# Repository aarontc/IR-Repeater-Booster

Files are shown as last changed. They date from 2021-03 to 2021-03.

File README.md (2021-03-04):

# IR Repeater Booster
This is a small electronic circuit to relay signals from an IR repeater over category (5/6) cabling using differential signalling to achieve very long runs.

It was based upon the ["Tunteil IR Remote Control Repeater"] from Amazon, sourced around December 2020. 
The device has a powered IR receiver that seems to accommodate a range of frequencies, operating from 5V DC and providing
an open-collector output. It then uses buffer transistors to drive up to 6 pairs of IR LEDs with a low value series resistor.

The IR receiver uses a 3.5mm TRS connector, where tip is output, ring is 5V, and sleeve is ground.

The Repeater Booster is designed to operate between the IR receiver and the "repeater" unit. 

This board is designed to be as inexpensive as is reasonably possible using JLCPCB's assembly service. 

["Tunteil IR Remote Control Repeater"]: https://amzn.to/3bettCj

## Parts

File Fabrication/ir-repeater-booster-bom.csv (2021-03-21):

Reference | Quantity | Value | Footprint | Datasheet | Description | JEDEC Package Name | Manufacturer Name | Manufacturer Part Number | Vendor 1 Link | Vendor 1 Name | Vendor 1 Part Number | Vendor 1 Price @1 | Vendor 1 Pricing Date | Package Comments
C1 C2 C3 C4 C5 C6 | 6 | 10u | Capacitor_SMD:C_1206_3216Metric | https://datasheet.lcsc.com/szlcsc/1810221112_Samsung-Electro-Mechanics-CL31A106KBHNNNE_C13585.pdf | 10uF ±10% 50V X5R 1206 Multilayer Ceramic Capacitors MLCC - SMD/SMT RoHS | 1206 | Samsung Electro-Mechanics | CL31A106KBHNNNE | https://lcsc.com/product-detail/Multilayer-Ceramic-Capacitors-MLCC-SMD-SMT_SAMSUNG_CL31A106KBHNNNE_10uF-106-10-50V_C13585.html/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 | LCSC | C13585 | $0.0611 | 2021-03-03
D1 | 1 | SS14 | Diode_SMD:D_SMA | https://datasheet.lcsc.com/szlcsc/2007141104_MDD-Microdiode-Electronics-SS14_C2480.pdf | 40V 1A 550mV @ 1A SMA(DO-214AC) Schottky Barrier Diodes (SBD) RoHS | DO-214AC | MDD(Microdiode Electronics) | SS14 | https://lcsc.com/product-detail/Schottky-Barrier-Diodes-SBD_MDD-Microdiode-Electronics-SS14_C2480.html/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 | LCSC | C2480 | $0.0164 | 2021-03-03
H1 H2 H3 H4 | 4 | MountingHole | MountingHole:MountingHole_3.2mm_M3 | ~
J1 | 1 | DC_IN | Connector_BarrelJack:BarrelJack_Wuerth_6941xx301002 | ~
J2 | 1 | RJ45_LED_Shielded | Footprints:RJ45-TH_B-1-1 | https://datasheet.lcsc.com/szlcsc/1811141116_BOOMELE-Boom-Precision-Elec-RJ45-B-1-1_C138392.pdf | RJ45 12 1 Through Hole Ethernet Connectors/Modular Connectors (RJ45 RJ11) RoHS |  | BOOMELE(Boom Precision Elec) | RJ45-B-1*1 | https://lcsc.com/product-detail/Ethernet-Connectors-Modular-Connectors-RJ45-RJ11_BOOMELE-Boom-Precision-Elec-RJ45-B-1-1_C138392.html/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 | LCSC | C138392 | $0.2518 | 2021-03-03
JP1 | 1 | Termination | Jumper:SolderJumper-2_P1.3mm_Bridged_RoundedPad1.0x1.5mm | ~
JP2 | 1 | Transmit | Jumper:SolderJumper-2_P1.3mm_Open_RoundedPad1.0x1.5mm | ~
R1 | 1 | 1k | Resistor_SMD:R_0603_1608Metric | https://datasheet.lcsc.com/szlcsc/1811141223_UNI-ROYAL-Uniroyal-Elec-0603WAF1001T5E_C21190.pdf | 1kΩ ±1% 0.1W ±100ppm/℃ 0603 Chip Resistor - Surface Mount RoHS | 0603 | UNI-ROYAL(Uniroyal Elec) | 0603WAF1001T5E | https://lcsc.com/product-detail/Chip-Resistor-Surface-Mount_Uniroyal-Elec-0603WAF1001T5E_C21190.html/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 | LCSC | C21190 | $0.0015 | 2013-03-03
R2 | 1 | 120 | Resistor_SMD:R_0603_1608Metric | https://datasheet.lcsc.com/szlcsc/1811021215_UNI-ROYAL-Uniroyal-Elec-0603WAF1200T5E_C22787.pdf | 120Ω ±1% 0.1W ±100ppm/℃ 0603 Chip Resistor - Surface Mount RoHS | 0603 | UNI-ROYAL(Uniroyal Elec) | 0603WAF1200T5E | https://lcsc.com/product-detail/Chip-Resistor-Surface-Mount_Uniroyal-Elec-0603WAF1200T5E_C22787.html/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 | LCSC | C22787 | $0.0014 | 2021-03-03
R3 | 1 | 10k | Resistor_SMD:R_0603_1608Metric | https://datasheet.lcsc.com/szlcsc/1811062009_UNI-ROYAL-Uniroyal-Elec-0603WAF1002T5E_C25804.pdf | 10kΩ ±1% 0.1W ±100ppm/℃ 0603 Chip Resistor - Surface Mount RoHS | 0603 | UNI-ROYAL(Uniroyal Elec) | 0603WAF1002T5E | https://lcsc.com/product-detail/Chip-Resistor-Surface-Mount_Uniroyal-Elec-0603WAF1002T5E_C25804.html/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 | LCSC | C25804 | $0.0016 | 2021-03-03
R4 | 1 | 560 | Resistor_SMD:R_0603_1608Metric | https://datasheet.lcsc.com/szlcsc/1811021213_UNI-ROYAL-Uniroyal-Elec-0603WAF5600T5E_C23204.pdf | 560Ω ±1% 0.1W ±100ppm/℃ 0603 Chip Resistor - Surface Mount RoHS | 0603 | UNI-ROYAL(Uniroyal Elec) | 0603WAF5600T5E | https://lcsc.com/product-detail/Chip-Resistor-Surface-Mount_Uniroyal-Elec-0603WAF5600T5E_C23204.html/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 | LCSC | C23204 | $0.0021 | 2021-03-20 | Imperial
R5 | 1 | 1k2 | Resistor_SMD:R_0603_1608Metric | https://datasheet.lcsc.com/szlcsc/1811021221_UNI-ROYAL-Uniroyal-Elec-0603WAF1201T5E_C22765.pdf | 1.2kΩ ±1% 0.1W ±100ppm/℃ 0603 Chip Resistor - Surface Mount RoHS | 0603 | UNI-ROYAL(Uniroyal Elec) | 0603WAF1201T5E | https://lcsc.com/product-detail/Chip-Resistor-Surface-Mount_Uniroyal-Elec-0603WAF1201T5E_C22765.html/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 | LCSC | C22765 | $0.0019 | 2021-03-20 | Imperial
TP1 | 1 | !RE | TestPoint:TestPoint_Pad_D2.0mm | ~
TP10 | 1 | GND | TestPoint:TestPoint_Pad_D2.0mm | ~
TP2 | 1 | DE | TestPoint:TestPoint_Pad_D2.0mm | ~
TP3 | 1 | RXD | TestPoint:TestPoint_Pad_D2.0mm | ~
TP4 | 1 | TXD | TestPoint:TestPoint_Pad_D2.0mm | ~
TP5 | 1 | A | TestPoint:TestPoint_Pad_D2.0mm | ~
TP6 | 1 | B | TestPoint:TestPoint_Pad_D2.0mm | ~
TP7 | 1 | 12V | TestPoint:TestPoint_Pad_D2.0mm | ~
TP8 | 1 | 5V | TestPoint:TestPoint_Pad_D2.0mm | ~
TP9 | 1 | 3V3 | TestPoint:TestPoint_Pad_D2.0mm | ~
TX1 RX1 | 2 | PJ-307C | Footprints:AUDIO-TH_PJ307C | https://datasheet.lcsc.com/szlcsc/1811040611_BOOMELE-Boom-Precision-Elec-PJ-307C_C16684.pdf | 3.5mm Plug-in headphone holder 5 Female Horizontal 3.5mm Audio & Video Connectors RoHS |  | BOOMELE(Boom Precision Elec) | PJ-307C | https://lcsc.com/product-detail/Audio-Video-Connectors_BOOMELE-Boom-Precision-Elec-PJ-307C_C16684.html | LCSC | C16684 | $0.0422 | 2021-03-03
U1 | 1 | HT7550-1 | Package_TO_SOT_SMD:SOT-89-3 | https://datasheet.lcsc.com/szlcsc/1811061932_Holtek-Semicon-HT7550-1_C16106.pdf | Fixed 30V 3.3V 55mV @ 1mA SOT-89(SOT-89-3) Dropout Regulators(LDO) RoHS | SOT-89-3 | Holtek Semicon | HT7550-1 | https://lcsc.com/product-detail/Low-Dropout-Regulators-LDO_HT7550-1_C16106.html/?href=jlc-SMT | LCSC | C16106 | $0.1669 | 2021-03-03
U2 | 1 | ST3485EBDR | Package_SO:SOIC-8_3.9x4.9mm_P1.27mm | https://datasheet.lcsc.com/szlcsc/1810181648_STMicroelectronics-ST3485EBDR_C75809.pdf | transceiver RS422, RS485 1/1 15Mbps SO-8 RS-485/RS-422 ICs RoHS | SO-8 | STMicroelectronics | ST3485EBDR | https://lcsc.com/product-detail/RS-485-RS-422-ICs_STMicroelectronics-ST3485EBDR_C75809.html/?href=jlc-SMT | LCSC | C75809 | $0.7574 | 2021-03-03
U3 | 1 | HT7533-1 | Package_TO_SOT_SMD:SOT-89-3 | https://datasheet.lcsc.com/szlcsc/1811062113_Holtek-Semicon-HT7533-1_C14289.pdf | Fixed 30V 3.3V 55mV @ 1mA SOT-89(SOT-89-3) Dropout Regulators(LDO) RoHS | SOT-89-3 | Holtek Semicon | HT7533-1 | https://lcsc.com/product-detail/Low-Dropout-Regulators-LDO_HT7533-1_C14289.html/?href=jlc-SMT | LCSC | C14289 | $0.1494 | 2021-03-03
U4 | 1 | 74HC14 | Package_SO:SOIC-14_3.9x8.7mm_P1.27mm | https://datasheet.lcsc.com/szlcsc/1811141851_Nexperia-74HC14D-653_C5605.pdf | 74HC Inverted器 6 6 2V ~ 6V SOIC-14_150mil Gates and Inverters RoHS | SOIC-14_150mil | Nexperia | 74HC14D,653 | https://lcsc.com/product-detail/74-Series_Nexperia_74HC14D-653_74HC14D-653_C5605.html/?href=jlc-SMT | LCSC | C5605 | $0.1116 | 2021-03-20 | SOIC-14_150mil

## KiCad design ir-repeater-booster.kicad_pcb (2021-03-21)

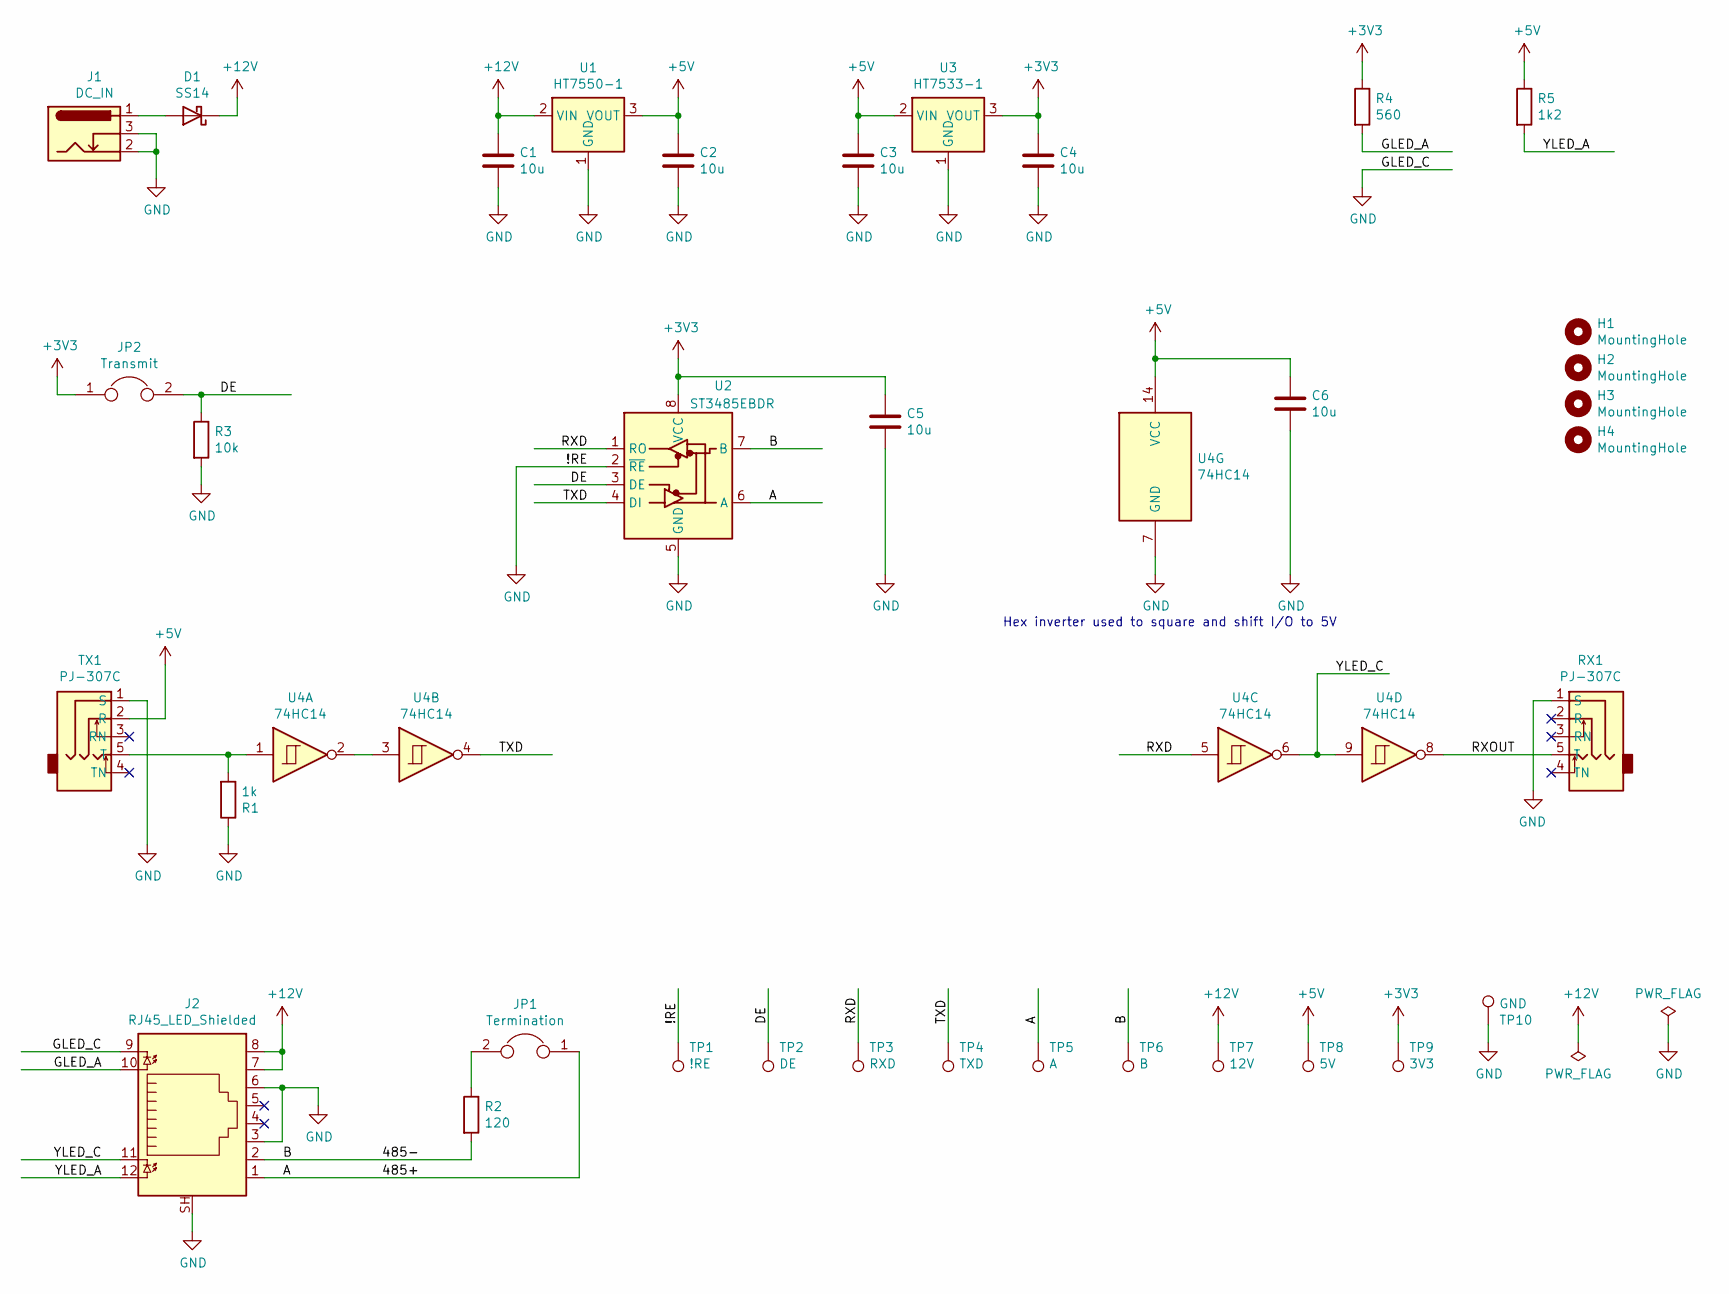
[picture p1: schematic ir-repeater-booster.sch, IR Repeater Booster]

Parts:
C1, C2, C3, C4, C5, C6: 10u; C_1206_3216Metric; Manufacturer Part Number CL31A106KBHNNNE
D1: SS14; D_SMA; Manufacturer Part Number SS14
H1, H2, H3, H4: MountingHole; MountingHole_3.2mm_M3
J1: DC_IN; BarrelJack_Wuerth_6941xx301002
J2: RJ45_LED_Shielded; RJ45-TH_B-1-1; Manufacturer Part Number RJ45-B-1*1
JP1: Termination; SolderJumper-2_P1.3mm_Bridged_RoundedPad1.0x1.5mm
JP2: Transmit; SolderJumper-2_P1.3mm_Open_RoundedPad1.0x1.5mm
R1: 1k; R_0603_1608Metric; Manufacturer Part Number 0603WAF1001T5E
R2: 120; R_0603_1608Metric; Manufacturer Part Number 0603WAF1200T5E
R3: 10k; R_0603_1608Metric; Manufacturer Part Number 0603WAF1002T5E
R4: 560; R_0603_1608Metric; Manufacturer Part Number 0603WAF5600T5E
R5: 1k2; R_0603_1608Metric; Manufacturer Part Number 0603WAF1201T5E
RX1: PJ-307C; AUDIO-TH_PJ307C; Manufacturer Part Number PJ-307C
TP1: !RE; TestPoint_Pad_D2.0mm
TP2: DE; TestPoint_Pad_D2.0mm
TP3: RXD; TestPoint_Pad_D2.0mm
TP4: TXD; TestPoint_Pad_D2.0mm
TP5: A; TestPoint_Pad_D2.0mm
TP6: B; TestPoint_Pad_D2.0mm
TP7: 12V; TestPoint_Pad_D2.0mm
TP8: 5V; TestPoint_Pad_D2.0mm
TP9: 3V3; TestPoint_Pad_D2.0mm
TP10: GND; TestPoint_Pad_D2.0mm
TX1: PJ-307C; AUDIO-TH_PJ307C; Manufacturer Part Number PJ-307C
U1: HT7550-1; SOT-89-3; Manufacturer Part Number HT7550-1
U2: ST3485EBDR; SOIC-8_3.9x4.9mm_P1.27mm; Manufacturer Part Number ST3485EBDR
U3: HT7533-1; SOT-89-3; Manufacturer Part Number HT7533-1
U4: 74HC14; SOIC-14_3.9x8.7mm_P1.27mm; Manufacturer Part Number 74HC14D,653

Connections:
+3V3: C4.1, C5.1, JP2.1, R4.1, TP9.1, U2.8 (VCC), U3.3 (VOUT)
+5V: C2.1, C3.1, C6.1, R5.1, TP8.1, TX1.2 (R), U1.3 (VOUT), U3.2 (VIN), U4.14 (VCC)
+12V: C1.1, D1.1 (K), J2.7, J2.8, TP7.1, U1.2 (VIN)
/485+: J2.1, JP1.1, TP5.1, U2.6 (A)
/485-: J2.2, R2.2, TP6.1, U2.7 (B)
/DE: JP2.2, R3.1, TP2.1, U2.3 (DE)
/GLED_A: J2.10, R4.2
/RXD: TP3.1, U2.1 (RO), U4.5
/RXOUT: RX1.5 (T), U4.8
/TXD: TP4.1, U2.4 (DI), U4.4
/YLED_A: J2.12, R5.2
/YLED_C: J2.11, U4.6, U4.9
GND: C1.2, C2.2, C3.2, C4.2, C5.2, C6.2, J1.2, J1.3, J2.3, J2.6, J2.9, J2.SH, R1.1, R3.2, RX1.1 (S), TP1.1, TP10.1, TX1.1 (S), U1.1 (GND), U2.2 (~RE), U2.5 (GND), U3.1 (GND), U4.7 (GND)
unnamed: D1.2 (A), J1.1
unnamed: JP1.2, R2.1
unnamed: R1.2, TX1.5 (T), U4.1
unnamed: U4.2, U4.3

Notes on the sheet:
Hex inverter used to square and shift I/O to 5V

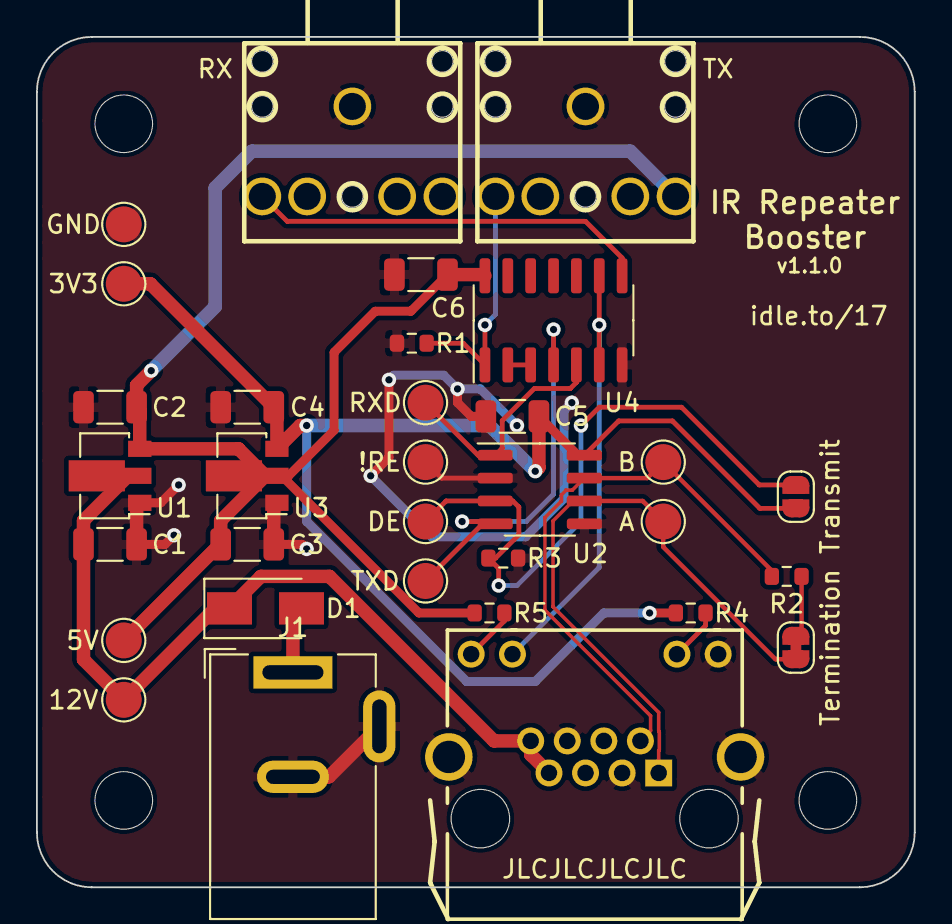
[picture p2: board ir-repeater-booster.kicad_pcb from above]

Board: 2 copper layers, 48.8 x 47.2 mm, 36 parts (0 on the bottom side), 17 nets.

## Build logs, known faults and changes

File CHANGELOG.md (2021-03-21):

# Changelog
All notable changes to this project will be documented in this file.

The format is based on [Keep a Changelog](https://keepachangelog.com/en/1.0.0/),
and this project adheres to [Semantic Versioning](https://semver.org/spec/v2.0.0.html).

## [1.1.0]

### Changed
- (Minor) Logic level inversion and translation with hex inverter

## [1.0.0]

### Added
- (Major) Initial repository layout and design capture

[Unreleased]: https://github.com/aarontc/ir-repeater-booster/

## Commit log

2021-03-04 Initial commit to backup schematic, should be ready for PCB layout
    [ir-repeater-booster.kicad_pcb, ir-repeater-booster.sch]
2021-03-06 Stashing progress
    [ir-repeater-booster.sch]
2021-03-06 Finishing work for 1.0.0 to fabricate
    [ir-repeater-booster-B_Cu.gbr, ir-repeater-booster-B_Mask.gbr, ir-repeater-booster-B_SilkS.gbr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]
2021-03-21 1.1.0 updates
    [ir-repeater-booster-B_Cu.gbr, ir-repeater-booster-B_Mask.gbr, ir-repeater-booster-B_SilkS.gbr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]
2021-03-21 Fix component position file for JLCPCB assembly
    [ir-repeater-booster-top-pos.csv]
